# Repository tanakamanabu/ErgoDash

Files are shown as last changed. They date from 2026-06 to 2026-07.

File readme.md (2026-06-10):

# About this fork

このリポジトリは [omkbd/ErgoDash](https://github.com/omkbd/ErgoDash) のフォークです。
既存の ErgoDash を改変し、キースイッチのソケット（ホットスワップ）対応版を作ることを目的としています。
オリジナルの ErgoDash については本家リポジトリを参照してください。

This repository is a fork of [omkbd/ErgoDash](https://github.com/omkbd/ErgoDash),
aiming to create a hot-swap socket compatible version of the ErgoDash.
For the original ErgoDash, please refer to the upstream repository.

---

# Notice

2019/5/5にファームウェアをアップデートしました。  
それ以前にハードウェアを作製されていた方はアップデートの必要はありませんが、  
アップデートした方は[ビルドガイドの最終項](https://github.com/omkbd/ErgoDash/blob/master/Doc/build.md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)を参照してください。

The firmware has been updated to 5/5/2019.  
If you have previously created hardware, you do not need to update, but if you have updated, please refer to [the last section of the build guide](https://github.com/omkbd/ErgoDash/blob/master/Doc/build-en.md#12-firmware).

# ErgoDash

ErgoDash

[Japanese Read me](https://github.com/omkbd/ErgoDash/blob/master/Doc/ergodash_jp.md)

# Layout

layout

# Parts

[ErgoDash PCB](https://github.com/omkbd/ErgoDash/tree/master/PCB)
 × 2  
[ErgoDash Case](https://github.com/omkbd/ErgoDash/tree/master/Case)
 × 2  
Switch (MX-compatible and Alps switches are supported) × 66-70  
Keycap × 66-70  
1N4148 diode × 66-70  
Arduino Pro Micro × 2  
TRRS jack MJ-4PP-9 × 2  
MJTP1117 switch × 2  
TRRS cable × 1  
Micro USB cable × 1  
M2×5mm screw × 22  
M2×8mm screw × 6  
M2×6mm spacer × 14  
Rubber feet × 8

---Option---  
LED WS2812B × 24  
LED 3mm × 66-70  
470Ω resistor × 66-70  
1kΩ resistor × 2  
NchMOSFET IRLML6344TRPbF × 2  

# Firmware

The ErgoDash uses QMK for its firmware, and the code for it is here:
[QMK - ErgoDash directory](https://github.com/qmk/qmk_firmware/tree/master/keyboards/ergodash)
.  

# Build Guide

[Japanese Build Guide](https://github.com/omkbd/ErgoDash/blob/master/Doc/build.md)  
[English Build Guide](https://github.com/omkbd/ErgoDash/blob/master/Doc/build-en.md)

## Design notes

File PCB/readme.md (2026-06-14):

# ErgoDash PCB

ErgoDash PCB  

## ソケット（ホットスワップ）対応版

Kailh ソケット対応の作業ディレクトリ（`socket-pcb` ブランチ）:

- `Rev1.2-socket-left/` — **左基板。設計の「正」**。ソケット対応の改変はここで行う
- `Rev1.2-socket-right/` — **右基板。左基板をフリップミラーして生成**したもの（手で直接編集しない）

本家由来の `Rev.1/` `Rev.1.1/` `Rev1.2/` は原則変更しない。詳細な設計方針はリポジトリ直下の `CLAUDE.md` を参照。

### ツールのパス

KiCad 10 同梱のものを使う:

- `kicad-cli` … `C:\Program Files\KiCad\10.0\bin\kicad-cli.exe`
- `python`（pcbnew 用）… `C:\Program Files\KiCad\10.0\bin\python.exe`

### ガーバー出力（推奨：スクリプト）

`PCB/gen_gerbers.ps1` で、各基板の `ergodash.kicad_pcb` からガーバー・ドリル・発注用 zip を
`<基板>/ergodash/` にまとめて再生成する。PowerShell で実行:

```powershell
cd PCB

# 両基板のガーバーを作り直す（各自で基板を編集済みの前提）
.\gen_gerbers.ps1

# 左を編集した後：右をミラー再生成してから両方出力
.\gen_gerbers.ps1 -Mirror

# 片方だけ
.\gen_gerbers.ps1 -Board left
```

発注時は `<基板>/ergodash/ergodash-socket-gerber.zip` をアップロードする。

### ガーバー出力（手動 CLI）

スクリプトを使わない場合は基板ごとに以下。`--board-plot-params` で基板に保存済みの
Plot 設定（出力先 `ergodash/`・レイヤ・Protel 拡張子）をそのまま使うのが要点。

```powershell
$cli = "C:\Program Files\KiCad\10.0\bin\kicad-cli.exe"
$d   = "Rev1.2-socket-left"   # 右なら Rev1.2-socket-right
Remove-Item "$d\ergodash\ergodash-*.g*","$d\ergodash\ergodash-*.drl","$d\ergodash\*.zip" -ErrorAction SilentlyContinue
& $cli pcb export gerbers --board-plot-params -o "$d\ergodash\" "$d\ergodash.kicad_pcb"
& $cli pcb export drill --format excellon --excellon-separate-th -o "$d\ergodash\" "$d\ergodash.kicad_pcb"
```

KiCad GUI なら **File → Plot**（設定は基板に保存済み）→ **Generate Drill Files...**（Excellon / PTH・NPTH 別）でも同じ結果。

### 右基板のミラー再生成

右基板は `mirror_right.py` で左基板をフリップミラー（基板外形の垂直中心軸で `Flip(LEFT_RIGHT)`）して作る。
全要素が B.Cu 側へ移り、ネットは不変（schematic-parity が保たれる）。`gen_gerbers.ps1 -Mirror` が内部でこれを呼ぶが、単体でも:

```powershell
$py = "C:\Program Files\KiCad\10.0\bin\python.exe"
& $py mirror_right.py Rev1.2-socket-right\ergodash.kicad_pcb
```

### 注意点

- **基板を編集したら必ずガーバーを作り直す**（GUI 保存も含む）。古いガーバーのまま発注しないこと。
- **右は左から再生成する**。左を直したら `gen_gerbers.ps1 -Mirror` で右をミラー → 両方出力。右の `.kicad_pcb` を手編集しない。
- **左右の `.kicad_sch` は同一に保つ**（電気設計は左右共通。ミラーはネットを変えない）。
- **KiCad GUI を開いたまま実行しても可**（基板ファイルは読むだけ）。ただし GUI に未保存編集があると古い状態で出力されるので、先に保存する。
- ドリル・Edge_Cuts はヘッダのタイムスタンプで毎回 diff が出るが、形状は不変なので気にしなくてよい。
- **発注前に必ずガーバービューア（KiCad GerbView か発注先のプレビュー）で目視確認**。
- `gen_gerbers.ps1` は日本語コメントを含むため **UTF-8 BOM 付き**で保存すること（Windows PowerShell 5.1 は BOM なしだと文字化けして構文エラーになる）。

## 変更履歴

### [rev.1.1]
・圧電スピーカーを追加（試験的）  
・上記に伴うパーツの配置を調整  
・シルク表記を追加

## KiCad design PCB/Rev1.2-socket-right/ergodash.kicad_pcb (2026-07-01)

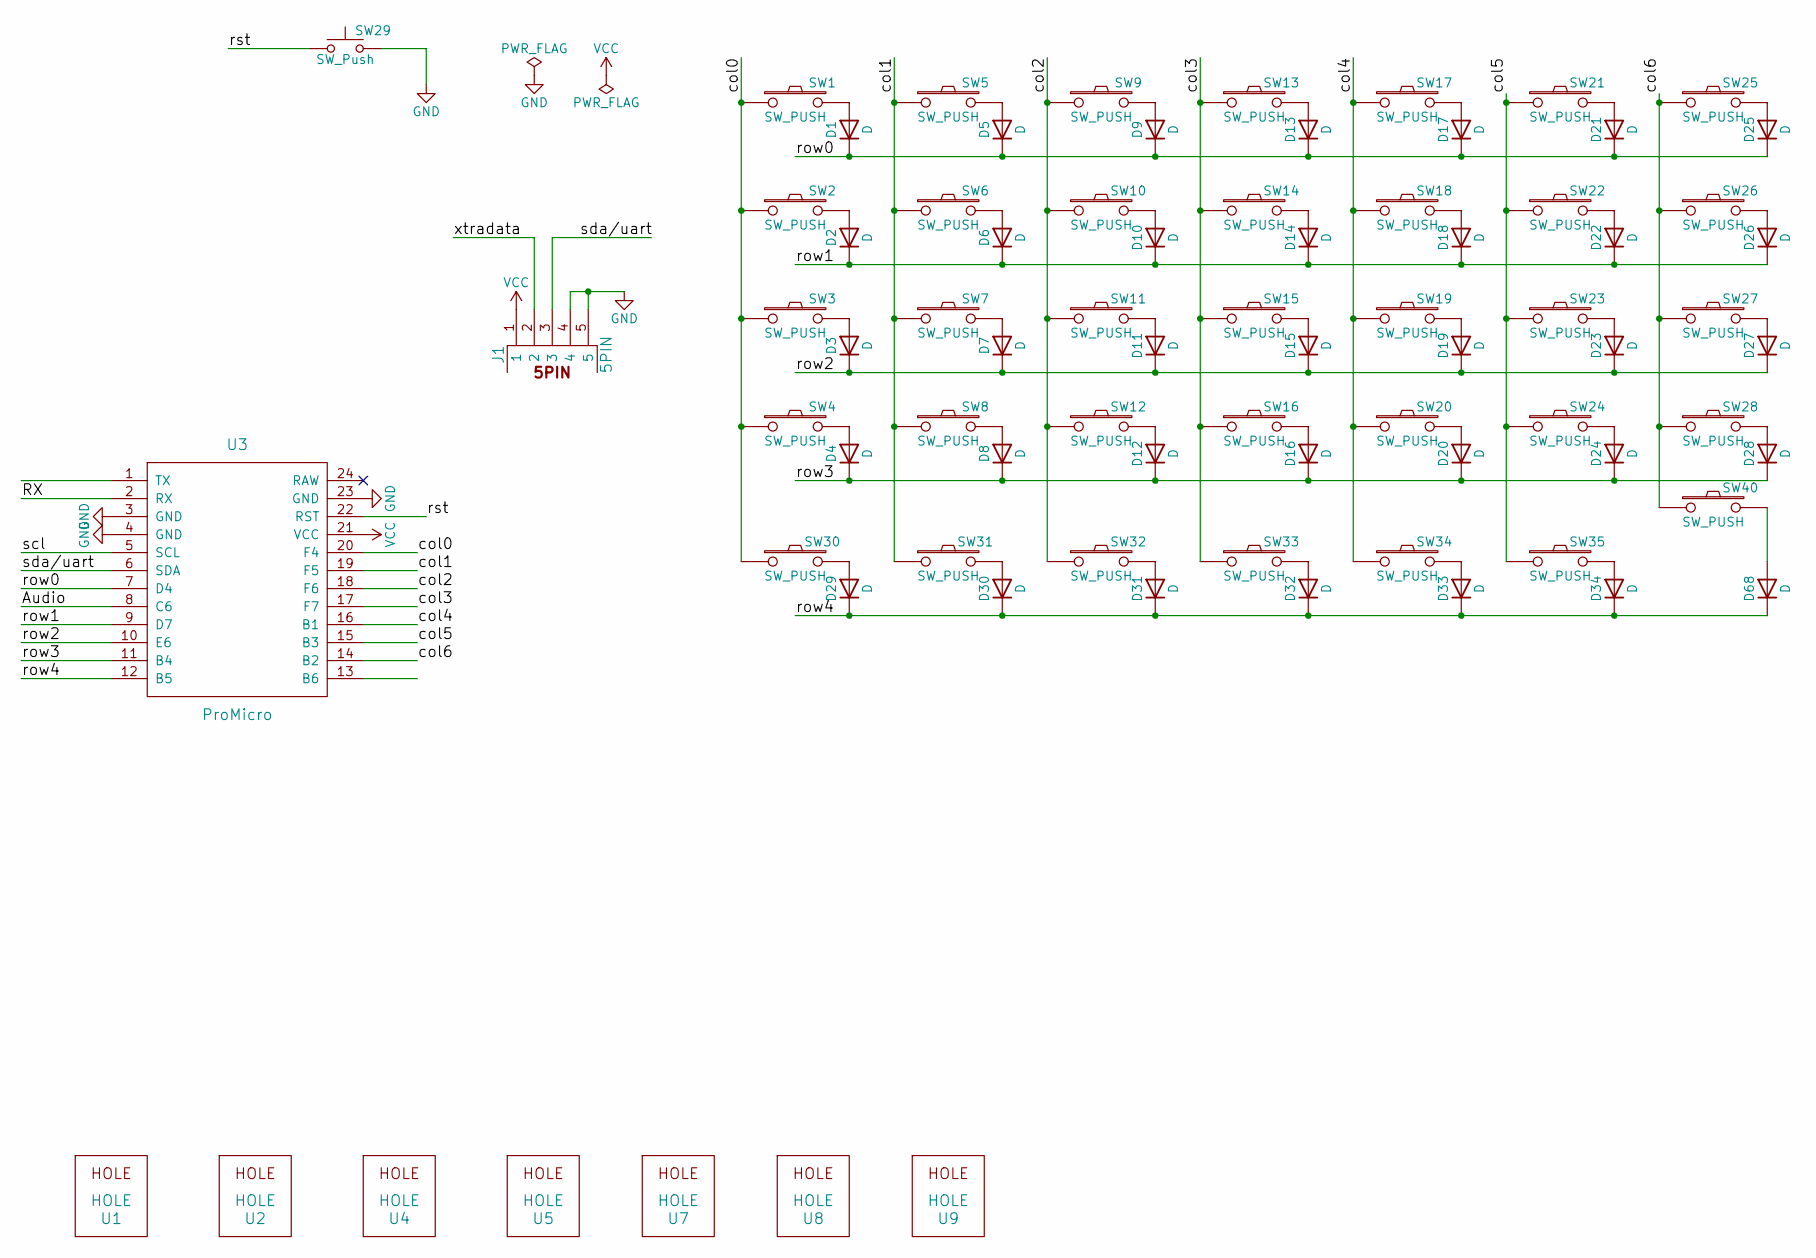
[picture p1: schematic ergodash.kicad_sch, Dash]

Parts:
D1, D2, D3, D4, D5, D6, D7, D8, D9, D10, D11, D12, D13, D14, D15, D16, D17, D18, D19, D20, D21, D22, D23, D24, D25, D26, D27, D28, D29, D30, D31, D32, D33, D34: D; Diode_SMD_THT3
D68: D; Diode_SMD_THT2
J1: 5PIN; trrs_jack2
SW1, SW2, SW3, SW4, SW5, SW6, SW7, SW8, SW9, SW10, SW11, SW12, SW13, SW14, SW15, SW16, SW17, SW18, SW19, SW20, SW21, SW22, SW23, SW24, SW25, SW26, SW27, SW28, SW30, SW31, SW32, SW33, SW34, SW35, SW40: SW_PUSH; SW_Hotswap_Kailh_MX_Plated
SW29: SW_Push; tact_switch2
U1, U2, U4, U5, U7, U8, U9: HOLE; hole
U3: ProMicro; ProMicro_rev

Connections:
/Audio: U3.8 (C6)
/RX: U3.2 (RX)
/col0: SW1.1, SW2.1, SW3.1, SW4.1, SW30.1, U3.20 (F4)
/col1: SW5.1, SW6.1, SW7.1, SW8.1, SW31.1, U3.19 (F5)
/col2: SW9.1, SW10.1, SW11.1, SW12.1, SW32.1, U3.18 (F6)
/col3: SW13.1, SW14.1, SW15.1, SW16.1, SW33.1, U3.17 (F7)
/col4: SW17.1, SW18.1, SW19.1, SW20.1, SW34.1, U3.16 (B1)
/col5: SW21.1, SW22.1, SW23.1, SW24.1, SW35.1, U3.15 (B3)
/col6: SW25.1, SW26.1, SW27.1, SW28.1, SW40.1, U3.14 (B2)
/row0: D1.1 (K), D5.1 (K), D9.1 (K), D13.1 (K), D17.1 (K), D21.1 (K), D25.1 (K), U3.7 (D4)
/row1: D2.1 (K), D6.1 (K), D10.1 (K), D14.1 (K), D18.1 (K), D22.1 (K), D26.1 (K), U3.9 (D7)
/row2: D3.1 (K), D7.1 (K), D11.1 (K), D15.1 (K), D19.1 (K), D23.1 (K), D27.1 (K), U3.10 (E6)
/row3: D4.1 (K), D8.1 (K), D12.1 (K), D16.1 (K), D20.1 (K), D24.1 (K), D28.1 (K), U3.11 (B4)
/row4: D29.1 (K), D30.1 (K), D31.1 (K), D32.1 (K), D33.1 (K), D34.1 (K), D68.1 (K), U3.12 (B5)
/rst: SW29.1, U3.22 (RST)
/scl: U3.5 (SCL)
/sda/uart: J1.3, U3.6 (SDA)
/xtradata: J1.2
GND: J1.4, J1.5, SW29.2, U3.3 (GND), U3.4 (GND), U3.23 (GND)
unnamed: D1.2 (A), SW1.2
unnamed: D2.2 (A), SW2.2
unnamed: D3.2 (A), SW3.2
unnamed: D4.2 (A), SW4.2
unnamed: D5.2 (A), SW5.2
unnamed: D6.2 (A), SW6.2
unnamed: D7.2 (A), SW7.2
unnamed: D8.2 (A), SW8.2
unnamed: D9.2 (A), SW9.2
unnamed: D10.2 (A), SW10.2
unnamed: D11.2 (A), SW11.2
unnamed: D12.2 (A), SW12.2
unnamed: D13.2 (A), SW13.2
unnamed: D14.2 (A), SW14.2
unnamed: D15.2 (A), SW15.2
unnamed: D16.2 (A), SW16.2
unnamed: D17.2 (A), SW17.2
unnamed: D18.2 (A), SW18.2
unnamed: D19.2 (A), SW19.2
unnamed: D20.2 (A), SW20.2
unnamed: D21.2 (A), SW21.2
unnamed: D22.2 (A), SW22.2
unnamed: D23.2 (A), SW23.2
unnamed: D24.2 (A), SW24.2
unnamed: D25.2 (A), SW25.2
unnamed: D26.2 (A), SW26.2
unnamed: D27.2 (A), SW27.2
unnamed: D28.2 (A), SW28.2
unnamed: D29.2 (A), SW30.2
unnamed: D30.2 (A), SW31.2
unnamed: D31.2 (A), SW32.2
unnamed: D32.2 (A), SW33.2
unnamed: D33.2 (A), SW34.2
unnamed: D34.2 (A), SW35.2
unnamed: D68.2 (A), SW40.2
VCC: J1.1, U3.21 (VCC)

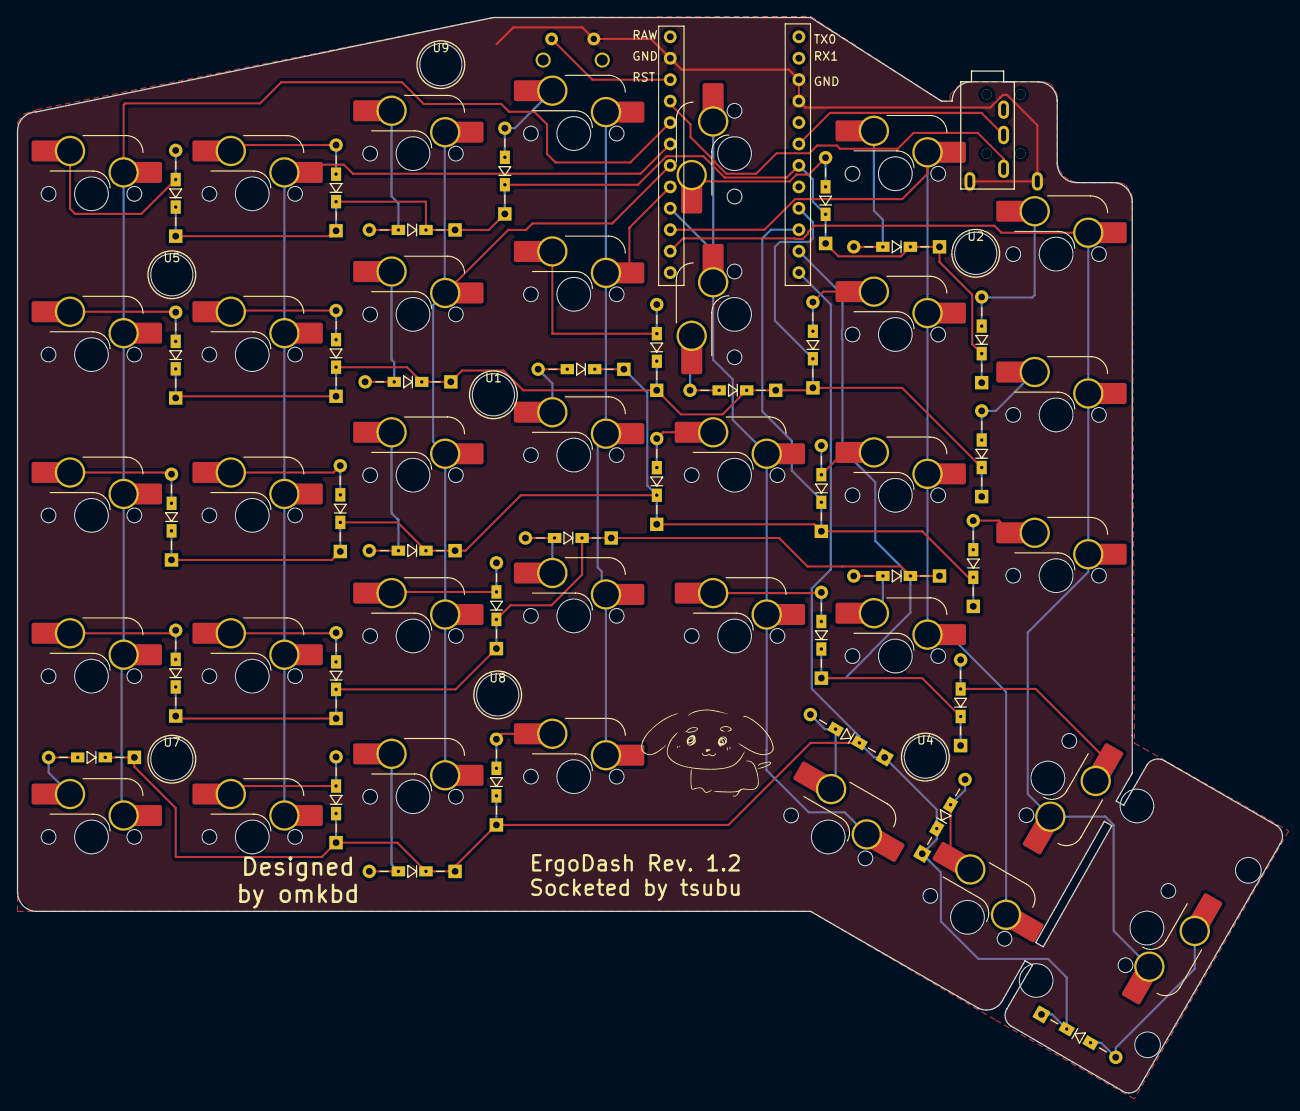
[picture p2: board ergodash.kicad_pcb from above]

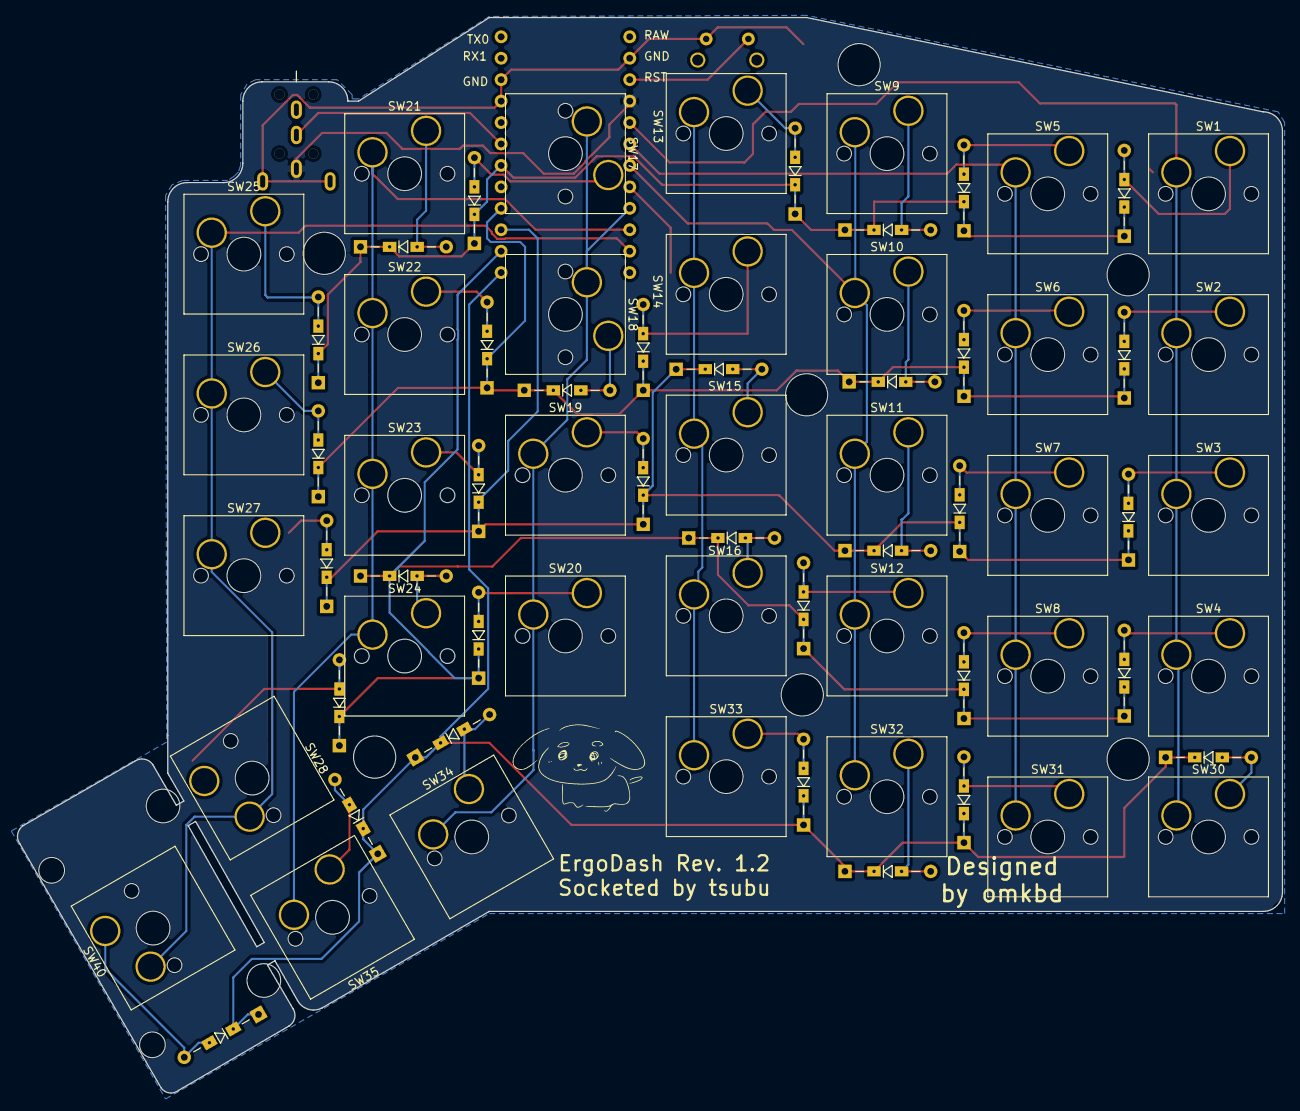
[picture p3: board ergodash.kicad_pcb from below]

Board: 2 copper layers, 149.9 x 127.4 mm, 80 parts (36 on the bottom side), 51 nets.

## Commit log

2026-06-10 Copy PCB Rev1.2 as base for socket version
    [ergodash.drl, ergodash.gbl, ergodash.gbo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]
2026-06-10 Document Rev1.2-socket as the development target in CLAUDE.md
2026-06-10 Convert Rev1.2-socket project to KiCad 10 format
    Open the legacy KiCad 5 project in KiCad 10 and save schematic and
    board in the new format. Remove the legacy files (.pro/.sch/.net and
    cache library) since symbols are now embedded in the .kicad_sch.
    Ignore KiCad temporary files (.history/, lock files, backups).
    [ergodash.kicad_pcb, ergodash.kicad_sch, ergodash.sch]
2026-06-10 Fix broken symbol resolution in KiCad 10 conversion
    The first conversion silently dropped every custom symbol
    (SW_PUSH, ProMicro, WS2812B, connectors, ...) because the legacy
    schematic references libraries by their original nicknames while
    KiCad only registered the cache library as ergodash-cache,
    leaving those symbols pinless and disconnecting the switch matrix,
    GND and more.
    Split ergodash-cache.lib into per-nickname libraries under
    library/ and register them in sym-lib-table, then re-import the
    schematic. The exported netlist now matches the original
    Rev1.2 netlist exactly (all 111 nets identical in membership).
    Drop the legacy source files again now that the conversion is
    verified.
    Co-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
    [ergodash.kicad_sch]
2026-06-10 Add Kailh hotswap socket footprints and record design decisions
    Vendor the Plated MX hotswap footprints from kiswitch
    (MIT/CC-BY-SA) into socket.pretty and register it in fp-lib-table.
    Record the socket-version design policy in CLAUDE.md: separate
    left/right boards instead of the reversible PCB, drop all LED
    options, Kailh PG1511 sockets (no more Alps support).
2026-06-10 Remove all LED options from the schematic
    Per the socket-version design policy: delete the WS2812B underglow
    chain (LED1-12), per-switch 3mm backlight LEDs (D35-D67, D69-D73),
    their 470 ohm resistors (R3-R12, R14-R39), the backlight driver
    (Q1, R13) and the LED connectors/jumpers (J2-J5).
    Verified by netlist diff against upstream Rev1.2: all 55 remaining
    key-matrix/power/TRRS nets are identical in membership; the only
    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
    [ergodash.kicad_sch]
2026-06-10 Assign Kailh hotswap socket footprint to all key switches
    Point the 39 SW_PUSH symbols at socket:SW_Hotswap_Kailh_MX_Plated
    and fix the TRRS jack footprint reference to match the footprint
    actually used on the board (trrs_jack2). Netlist unchanged.
    [ergodash.kicad_sch]
2026-06-10 Remove silkscreen logos and protect stabilizers from sync deletion
    Drop the decorative logo footprints and mark the two 2U stabilizer
    footprints as board-only so that updating the PCB from the schematic
    with orphan deletion enabled will not remove them. Includes the
    KiCad 10 resave of the board file.
    [ergodash.kicad_pcb]
2026-06-10 Sync board with socket schematic and clean up stale copper
    Board-side result of the LED removal and switch footprint swap:
    flip the 13 back-side socket footprints to the front (left-hand
    board is no longer reversible), delete old tracks and vias that
    shorted against or crowded the new socket pads, and refill the
    copper zones. DRC violations drop from 1004 to 408; the remaining
    ones are diode placement conflicts, rerouting work and alternative
    layout courtyard overlaps to be resolved in the layout phase.
    [ergodash.kicad_pcb]
2026-06-11 Resolve socket collisions around the Pro Micro
    The hotswap socket pads of the four keys above the controllers
    shorted against Pro Micro pin pads. Fix in three parts: exclude U6
    (the right-hand controller, unused on the left board) from the
    board via on_board=no, rotate SW13/SW14 by 270 degrees so their
    socket wings thread the corridor between the U3 pin columns
    (min copper gap 0.27mm), and remove the stale tracks under the
    rotated pads. Netlist diff confirms the only schematic change is
    U6 dropping out of the PCB netlist.
    Also includes manual diode repositioning done in the GUI.
    [ergodash.kicad_pcb, ergodash.kicad_sch]
2026-06-12 Route the left board and drop alternative key layouts
    Manual routing of the key matrix done in the GUI. Remove the
    alternative-position switches (SW36, SW38, SW39, SW41) from the
    schematic, keeping SW40 as the only 2U key, and delete the now
    orphaned 2U stabilizer at the old SW36 position, which also
    resolves the hole clearance conflict with the SW35 socket pad.
    Re-apply the U6 on_board=no exclusion that was lost to a
    concurrent eeschema save.
    [ergodash.kicad_pcb, ergodash.kicad_sch]
2026-06-12 Exclude SW37 (right-hand reset switch) from the left board
    SW37 is the back-side reset switch used when the reversible board
    served as the right half, so the left board does not need it.
    Exclude it via on_board=no like U6 instead of moving it away from
    the SW13 socket pad it overlapped. Also refill zones (clears stale
    VCC fill under new row3 tracks) and document the thumb layout
    decision in CLAUDE.md.
    [ergodash.kicad_pcb, ergodash.kicad_sch]
2026-06-12 Finish left board routing and modernize solder mask clearance
    Final GND island link routed in the GUI completes the board:
    0 unconnected, 0 shorts, 0 clearance violations, and the pad
    connectivity matches the schematic netlist exactly (all 55 nets).
    Change pad_to_mask_clearance from the KiCad 5 era 0.2mm to 0 so
    mask apertures no longer merge between nearby pads; this also
    restores a solder dam in the tight SW13/U3 corridor. Remaining
    DRC notes are accepted by design: U3 pin holes inside socket
    courtyards (controller under the keys), positioning holes inside
    courtyards, and one col6 track passing under the SW25 socket body.
    [ergodash.kicad_pcb]
2026-06-12 Remove I2C/speaker options, add mascot logo, regenerate gerbers
    - Remove the unpopulated I2C provision (pull-ups R1/R2, jumper W1) from
    schematic and board with its dead copper; split communication is QMK
    serial only (split.serial pin D0 = /sda/uart)
    - Remove speaker M1 and its 1k resistor R40 (undocumented option absent
    from the build guide and shop list)
    - Delete orphaned silk labels of removed options (V/G/RGB/I2C/Xtra/TX0/
    BL1k/Au1k); only the two nameplates remain, now reading
    "ErgoDash Rev. 1.2 / Socketed by tsubu" (also fixes the "Soket" typo)
    - Restore bottom-row socket references SW30-SW35 that had drifted one
    step from the schematic (duplicate SW29, missing SW35)
    - Add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
    [ergodash-B_Cu.gbl, ergodash-B_Mask.gbs, ergodash-B_Silkscreen.gbo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]
2026-06-13 Generate right-hand socket board by mirroring the left
    Rename PCB/Rev1.2-socket to Rev1.2-socket-left and add Rev1.2-socket-right
    generated via PCB/mirror_right.py, which flips every element (footprints,
    tracks, zones, drawings) across the board-outline vertical axis using
    Flip(LEFT_RIGHT). All parts move to B.Cu, matching the original ErgoDash
    right-hand convention. Schematic/netlist is identical (flip preserves nets;
    schematic-parity passes), DRC matches the left board with no new violations.
    Also fix D68 silkscreen: it used the single-sided Diode_SMD_THT2 footprint
    unlike the other 34 diodes (double-sided THT3), so its diode symbol vanished
    from F.Silkscreen after the flip. Added the B.S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
    [ergodash-B_Cu.gbl, ergodash-B_Mask.gbs, ergodash-B_Silkscreen.gbo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]
2026-06-13 Reposition "Designed by omkbd" nameplate and refresh gerbers
    Manual silkscreen tweak: the "Designed by omkbd" nameplate was moved on
    both boards in KiCad (left B.SilkS, right F.SilkS). Regenerate gerbers and
    drill for both halves so the fabrication data matches the board.
    [ergodash-B_Cu.gbl, ergodash-B_Mask.gbs, ergodash-B_Silkscreen.gbo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]
2026-06-13 Add gen_gerbers.ps1 and document the gerber workflow
    PCB/gen_gerbers.ps1 regenerates gerbers/drill/zip for both socket boards
    using each board's saved plot params, with an optional -Mirror switch that
    re-derives the right board from the left first. Document the socket board
    layout, the script, manual CLI/GUI fallbacks, the mirror step, and caveats
    in PCB/readme.md.
2026-06-13 Stamp the right board title block as Socket-right
    After flipping, mirror_right.py inherited the left board's "...-left" title
    block. Swap "left"->"right" in the title so the generated right board is
    self-describing. Title block is metadata only and does not affect gerbers.
2026-06-14 Remove vestigial U6, add Pro Micro pin labels, refresh both boards
    Schematic cleanup: delete U6 (the right-hand Pro Micro left over from the
    original reversible design) from both halves' schematics. It was on_board=no
    so it never appeared in the netlist or on the board; removing it just drops
    dead symbols. Both schematics remain electrically identical.
    Left board: add silkscreen pin-name labels (RAW/GND/RST/VCC/TX0/RX1...) around
    the Pro Micro, and stamp the title block as Socket-left.
    Right board: re-mirror from the left so it inherits the new pin labels and is
    stamped Socket-right (mirror_right.py now swaps the title). Regenerate gerbers
    and drill for both halves.
    DRC: left 130 / right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
    [ergodash-B_Cu.gbl, ergodash-B_Mask.gbs, ergodash-B_Silkscreen.gbo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]
2026-06-20 WIP: flip left-board sockets to front (geometry only)
    Stage 1 of the socket-on-front re-layout (Option B). Every keyswitch/socket
    footprint is flipped in place via flip_sockets_front.py so the Kailh socket SMD
    pads now mount on F.Cu and the switch through-holes move to the back-insertion
    (left-right mirrored) MX pattern.
    This intentionally leaves the matrix DISCONNECTED (71 unconnected items): the old
    traces fed the B.Cu socket pads / old hole positions. Matrix rerouting is the
    next stage, done by hand in KiCad.
    [ergodash.kicad_pcb]
2026-06-20 Rotate SW35/SW40 so flipped sockets sit on the board
    After flipping the sockets to the front, the SMD socket pads of two edge thumb
    keys overhung the board outline (DRC copper_edge_clearance 0.0 mm). Rotate them
    back onto the board, folded into flip_sockets_front.py for reproducibility:
    - SW40 (2U): +180 deg only (90 would make it a vertical 2U)
    - SW35 (1U square): +270 deg
    Board now has zero copper_edge_clearance violations. Matrix still unrouted
    (69 unconnected) -- routing is the next stage.
    [ergodash.kicad_pcb]
2026-06-20 WIP: matrix routing in progress (KiCad GUI)
    Snapshot of in-progress hand-routing on the flipped-socket board before the
    left/right directory rename, so the routing work is preserved across the move.
    [ergodash.kicad_pcb]
2026-06-20 Swap socket-left/right dirs to match the actual hand
    The board in Rev1.2-socket-left actually builds the RIGHT hand and vice versa:
    the components/sockets sit on F.Cu, which per the build guide is the underside
    (裏側), so the KiCad layout is the bottom view -- mirror-reversed from use. The
    inner-edge features (TRRS J1, 2U thumb SW40) are on +X, which maps to the left in
    use = a right-hand half.
    Swapped the two directories' contents and fixed the title blocks accordingly:
    Rev1.2-socket-right <- the active flipped-socket board (right hand, has the
    in-progress routing)
    Rev1.2-socket-left <- the old stale flip (NOTE: still a right-hand board, not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
    [ergodash-B_Cu.gbl, ergodash-B_Mask.gbs, ergodash-B_Silkscreen.gbo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]
2026-06-20 Revise CLAUDE.md for corrected left/right, sockets-on-front, no-mirror
    Reflects this session's findings:
    - F.Cu = 裏側 (component/socket side); B.Cu = 表側 (keycap side)
    - left/right directories were swapped vs the actual hand (fixed 2026-06-20):
    Rev1.2-socket-right = active right-hand board; Rev1.2-socket-left = stale
    - mirror generation is impossible (chiral switches); mirror_right.py is void;
    each hand is laid out independently and hand-routed
    - sockets flipped to F.Cu via flip_sockets_front.py; SW35/SW40 rotated to fit
    - KiCad 10 format now; gerbers are stale until rerouting is done
    - added open items: real left-hand board, per-hand Pro Micro selection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
2026-06-20 Remove obsolete mirror_right.py
    Mirror generation is impossible for a keyboard PCB (chiral MX switches have no
    mirror-image part), so the Flip-based mirror_right.py is void. Each hand is laid
    out independently now. See CLAUDE.md.
2026-06-20 WIP scaffold: relocate Pro Micro/reset to right-hand side (socket-right)
    Rough geometry placement only (per the keys-stay-put / A approach):
    - U3 (Pro Micro) -> X=163.2 on F.Cu (over the SW17/18 column)
    - SW29 (reset) -> X=144.0 on F.Cu
    - SW17/SW18 -> -90 deg, SW13/SW14 -> 180 deg (revert)
    This is a STARTING SCAFFOLD, not finished: SW17/SW18 sockets still collide with
    the Pro Micro pin rows and must be hand-threaded between them (~0.27mm, like the
    existing SW13/14), and the whole Pro Micro/reset area needs rerouting. Done by
    hand in KiCad.
    [ergodash.kicad_pcb]
2026-06-20 Complete right-hand board routing + regenerate gerbers (socket-right)
    socket-right (right hand) is now electrically complete:
    - matrix fully hand-routed (0 unconnected, 0 clearance/shorting/thermal/dangling)
    - Pro Micro relocated to the right-hand side (over SW17/18); SW17/18 threaded
    through its pin rows; SW13/14 reverted; reset moved
    - starved_thermal fixed (GND stub into the pour)
    - Default clearance relaxed to 0.2 mm (well within JLCPCB's 0.127 mm min) to
    clear the marginal pin-area clearances
    - silkscreen tidied
    Remaining DRC items are non-electrical (silk overlaps, lib_footprint notes, and
    the socket+switch shared-footprint courtyard overlaps = same as baseline).
    Gerbers + drills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
    [ergodash-B_Cu.gbl, ergodash-B_Mask.gbs, ergodash-B_Silkscreen.gbo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]
2026-06-20 Move U3 silkscreen to back + regenerate gerbers (socket-right)
    Pro Micro (U3) silkscreen moved to B.SilkS (footprint stays on F.Cu); gerbers,
    drills and the upload zip regenerated. Electrical DRC still clean (0 unconnected,
    0 clearance/shorting/thermal/dangling).
    [ergodash-B_Cu.gbl, ergodash-B_Mask.gbs, ergodash-B_Silkscreen.gbo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]
2026-06-28 Fix board-edge clearance on right-hand board + regenerate gerbers
    Resolve all 11 copper_edge_clearance errors from the previous commit
    (0 unrouted, 0 schematic-parity issues confirmed via kicad-cli DRC).
    Remaining courtyard violations are by design (U3 Pro Micro under keys,
    U1/U2 mounting holes). Regenerated gerbers/drill/zip in ergodash/.
    [ergodash-B_Cu.gbl, ergodash-B_Mask.gbs, ergodash-B_Silkscreen.gbo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]
2026-07-01 Move U3 outline silkscreen to front + regenerate gerbers (socket-right)
    Pro Micro (U3) footprint stays on B.Cu (needed so the USB port clears the
    board edge), but its outline markers were still on B.SilkS/B.Fab, making
    the mounting-side indicator show on the wrong physical face. Moved just
    the outline graphics (courtyard rectangle) to F.SilkS/F.Fab without
    touching pads or footprint placement. DRC confirms 0 unrouted, no new
    violations (silk_overlap actually dropped 38->33). Regenerated gerbers,
    drills and the upload zip in ergodash/.
    [ergodash-B_Cu.gbl, ergodash-B_Mask.gbs, ergodash-B_Silkscreen.gbo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]
